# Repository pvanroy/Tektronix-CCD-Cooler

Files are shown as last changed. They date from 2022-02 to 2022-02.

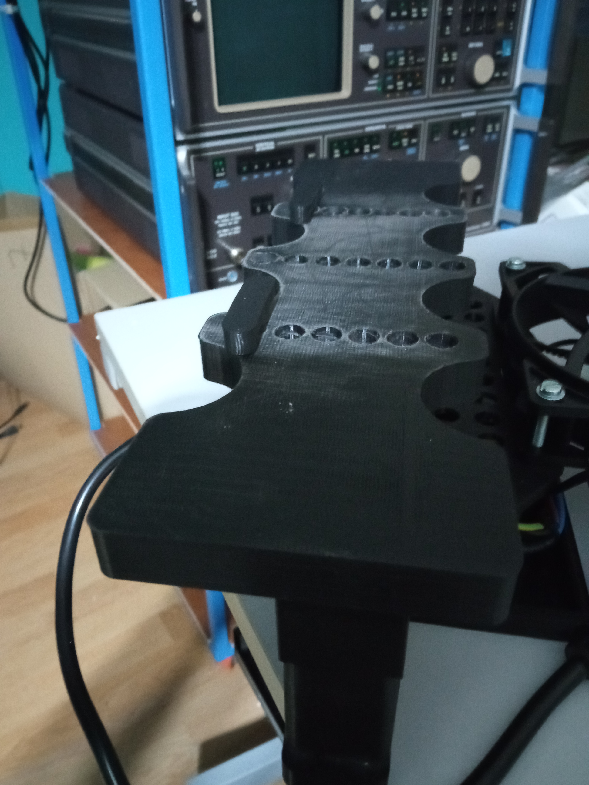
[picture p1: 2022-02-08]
Pictures/IMG_20220208_131840.jpg

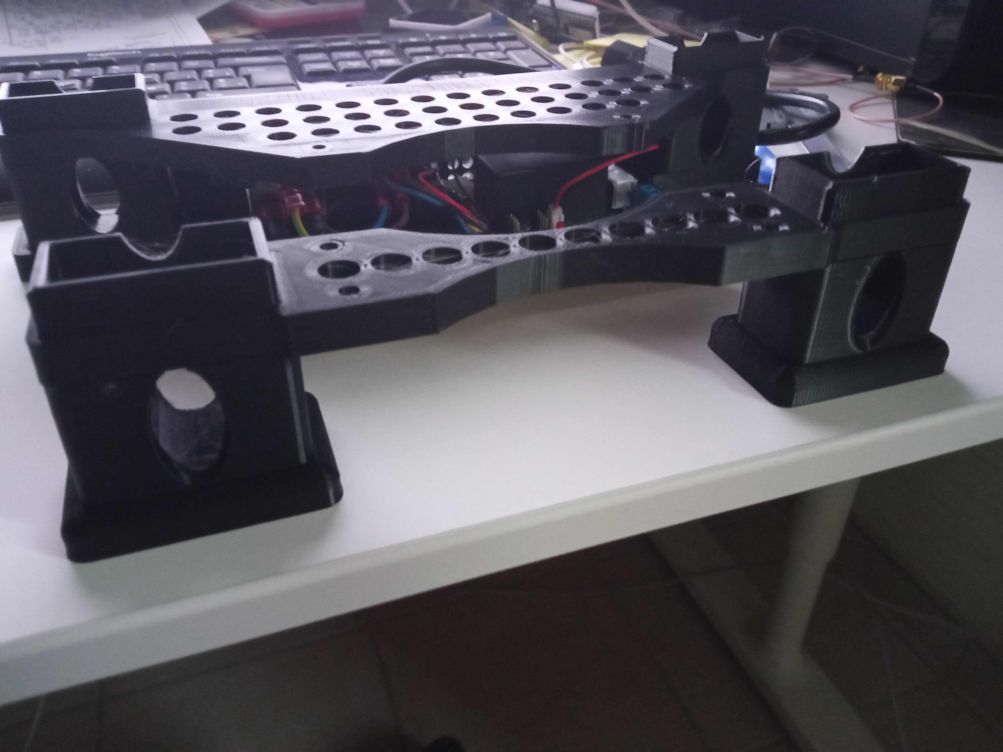
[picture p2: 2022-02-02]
Pictures/IMG_20220201_171502.jpg

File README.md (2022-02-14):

# Tektronix-CCD-Cooler
If you own a Tektronix 24xx series and you attempt a full calibration or just a repair, you have to be careful about the CCD memory section over heating!! This device will help you.
The "Cooler" is a 3D printed kit I designed. It’s made of several parts.
Two fans (120mmx120mmx25mm), are the main elements for this project. They are drived by a small switched power supply running 12V at 850mA. Fans are 120mA nominal consumption (per fan). A power cord is added to the rear for easily powered the scope under test. You can also add a speed controller at your discretion, there is room for it!

Title

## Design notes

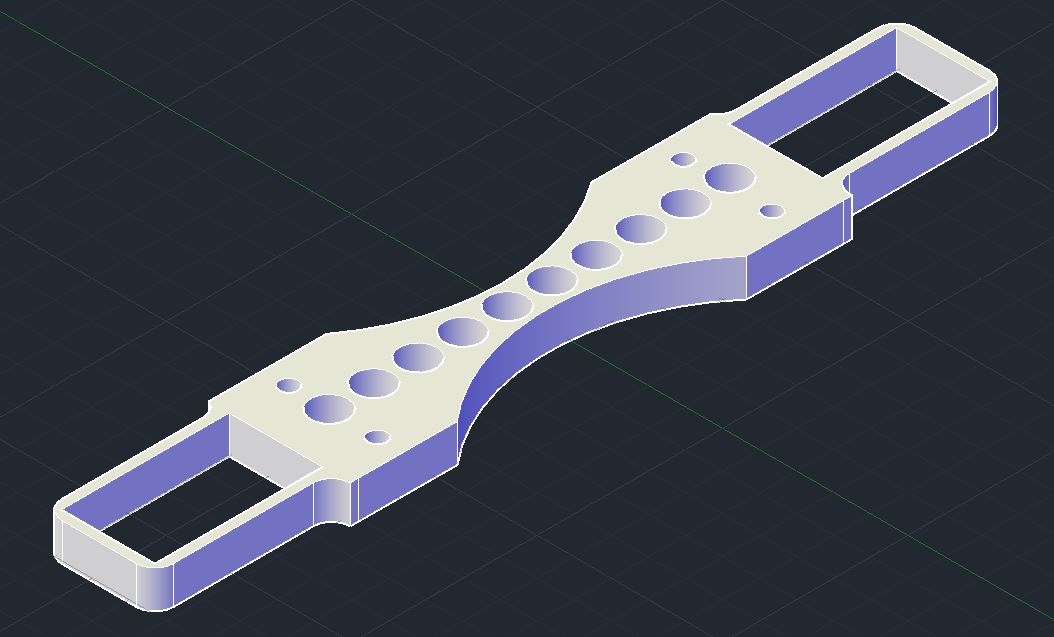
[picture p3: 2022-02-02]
Pictures/Center_Vent_Plate.JPG

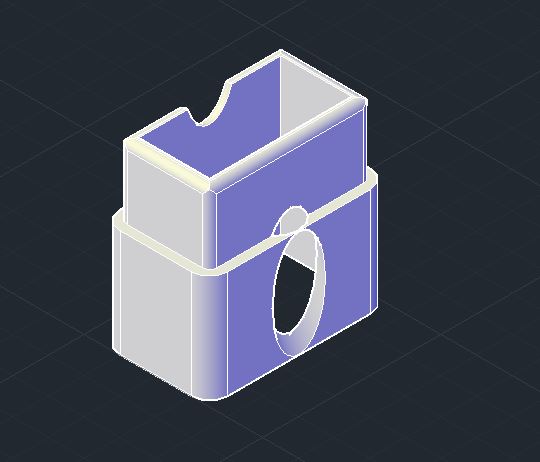
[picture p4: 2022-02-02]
Pictures/Feet.JPG

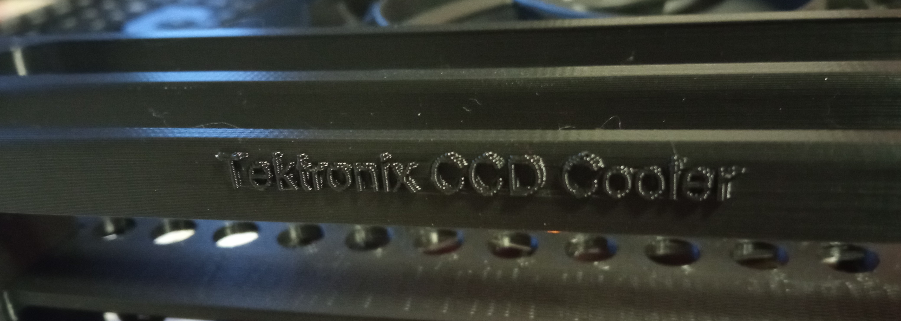
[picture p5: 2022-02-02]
Pictures/Title.jpg

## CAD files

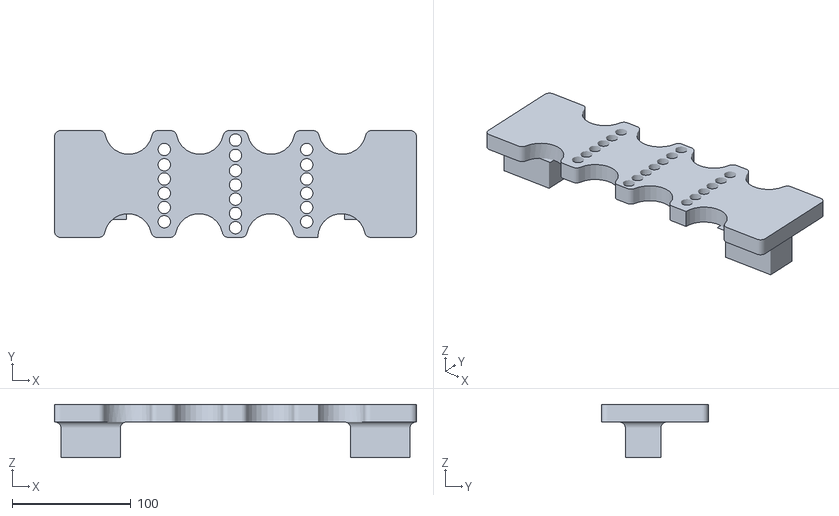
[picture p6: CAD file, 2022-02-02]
Stl's/CoolerBase_V1.1TowerSystem_TopRear.stl
305.0 x 90.0 x 45.0

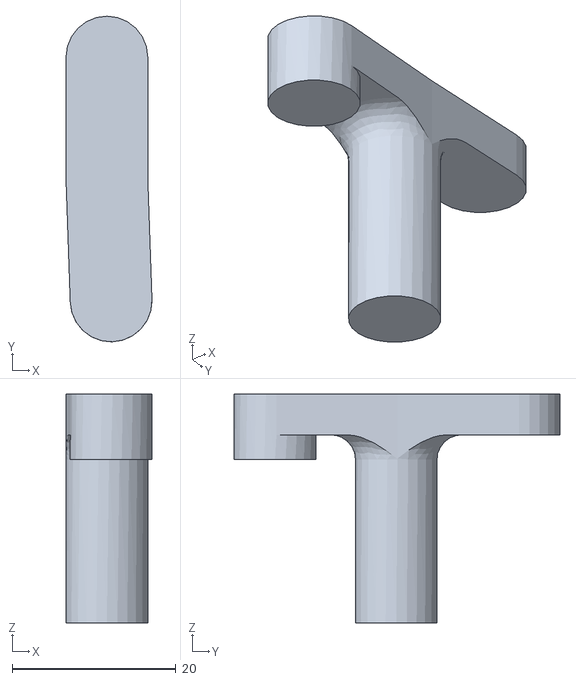
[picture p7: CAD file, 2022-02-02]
Stl's/CoolerBase_V1.1TowerSystem_Clamp.stl
10.5 x 39.8 x 28.0

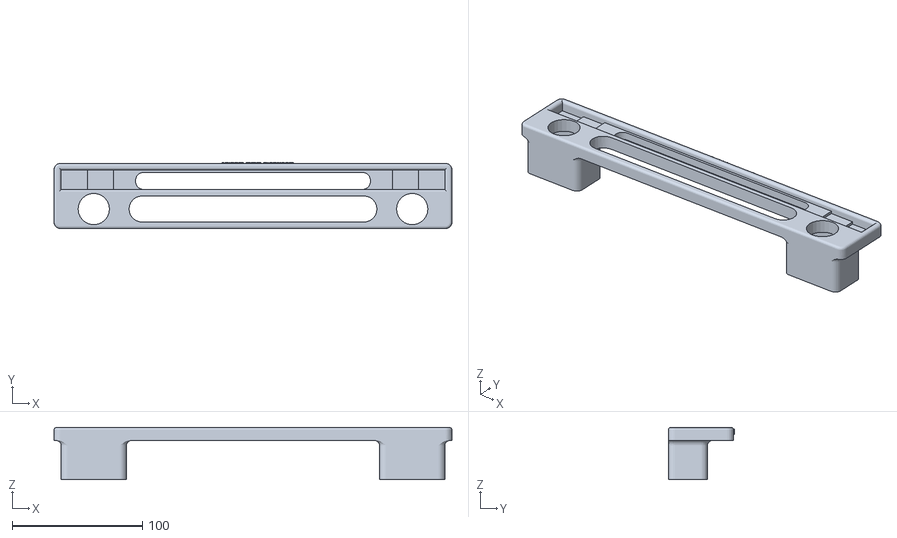
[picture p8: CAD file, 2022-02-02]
Stl's/CoolerBase_V1.1TowerSystem_TopFront.stl
305.0 x 50.8 x 40.0

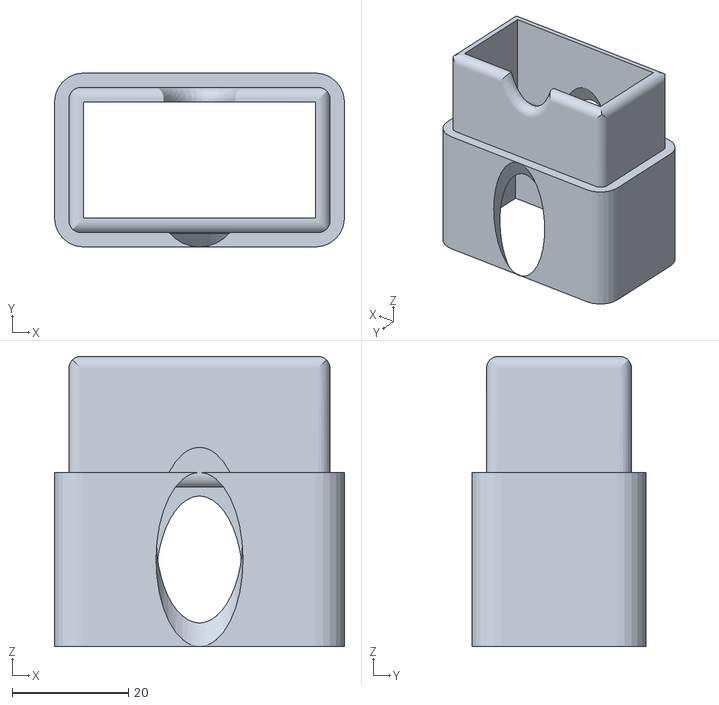
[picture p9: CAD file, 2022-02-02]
Stl's/Cooler_Base_V1.0_Tower_System_Columns.stl
50.0 x 30.0 x 50.0

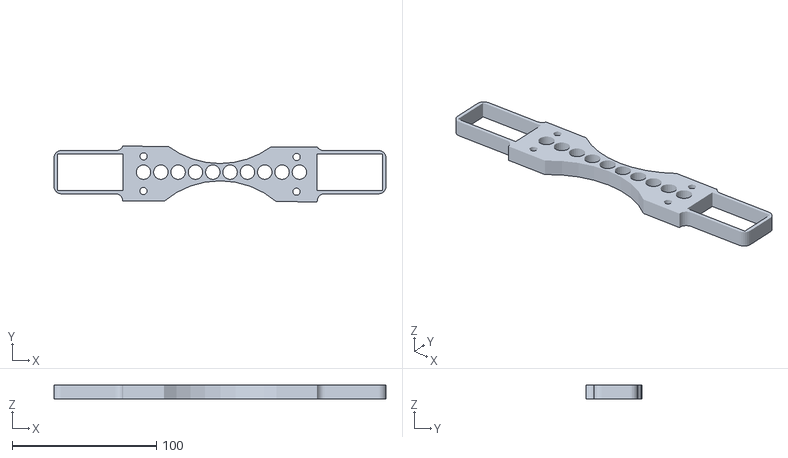
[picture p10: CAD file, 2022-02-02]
Stl's/Cooler_Base_V1.0_Tower_System_CenterVent.stl
230.0 x 38.5 x 10.00

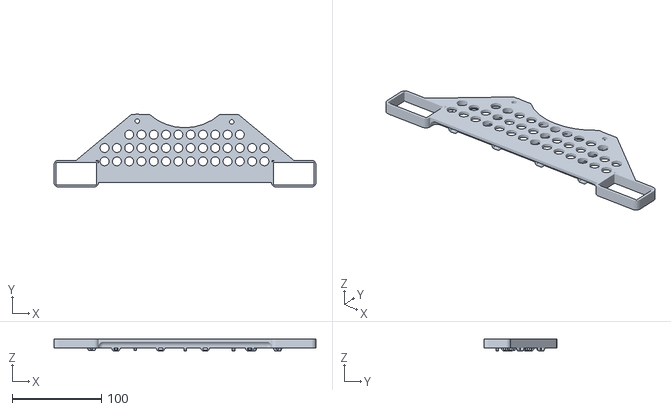
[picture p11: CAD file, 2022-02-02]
Stl's/Cooler_Base_V1.0_Tower_System_FrontVent.stl
294.0 x 81.9 x 13.0

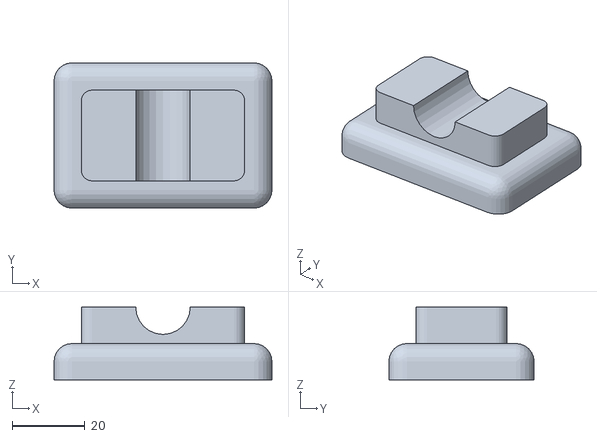
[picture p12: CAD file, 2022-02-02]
Stl's/CoolerBase_V1.1TowerSystem_Feet.stl
60.0 x 40.0 x 20.0

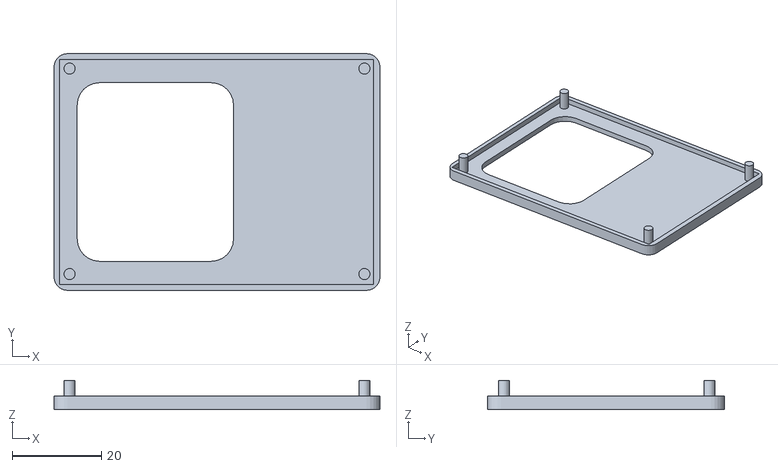
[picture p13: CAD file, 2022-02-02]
Stl's/CoolerBase_V1.1TowerSystem_Board_Support.stl
73.0 x 53.0 x 6.50

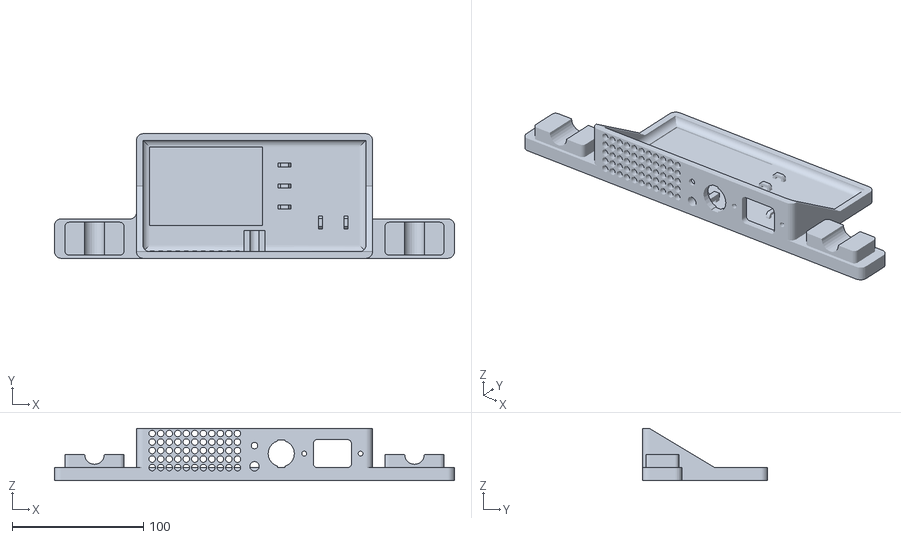
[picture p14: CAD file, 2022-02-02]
Stl's/Cooler_Base_V1.0_Tower_System_Power.stl
305.0 x 95.0 x 40.0

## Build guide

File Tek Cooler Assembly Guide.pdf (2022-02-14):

| 2022

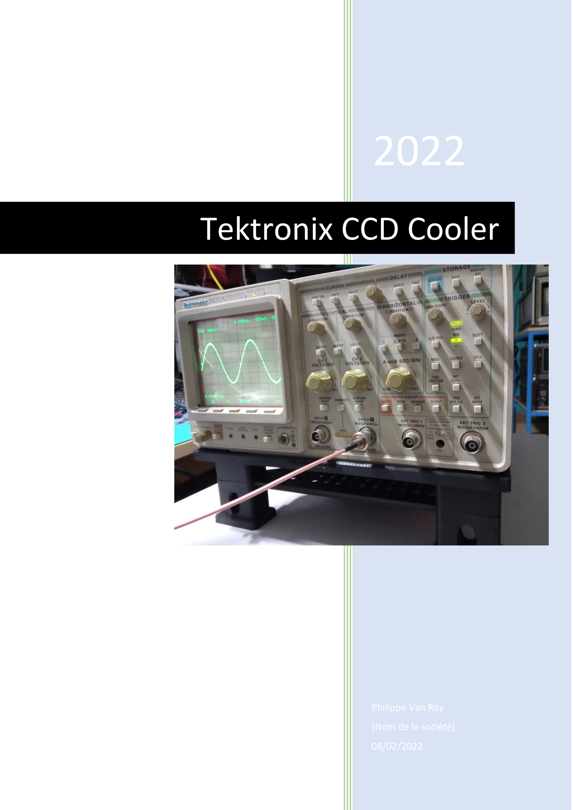
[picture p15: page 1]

# Tektronix CCD Cooler

Philippe Van Roy

[Nom de la société]

08/02/2022

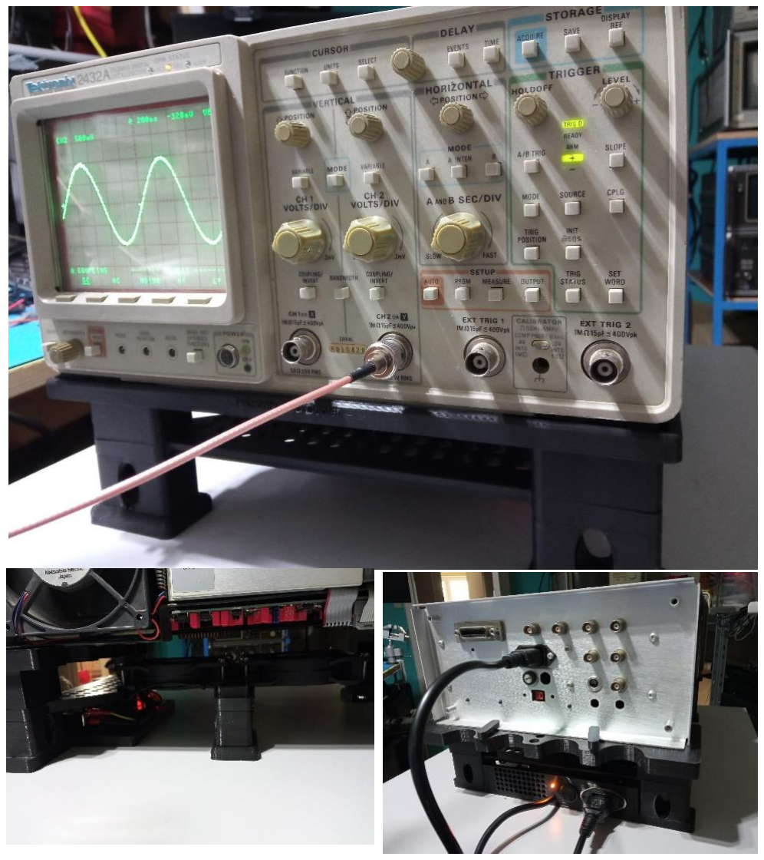
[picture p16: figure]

Philippe Van Roy, Belgium 2022 join our group : https://www.facebook.com/groups/570538600220141

TEKTRONIX CCD COOLER

Tektronix® CCD Cooler (Refroidisseur de CCD Tektronix)

If you own a Tektronix 24xx series and you attempt a full calibration or just a repair, you have to be careful about the CCD memory section over heating!! This device will help you.
The "Cooler" is a 3D printed kit I designed. It’s made of several parts.
Two fans (120mmx120mmx25mm), are the main elements for this project. They are drived by a small switched power supply running 12V at 850mA. Fans are 120mA nominal consumption (per fan). A power cord is added to the rear for easily powered the scope under test. You can also add a speed controller at your discretion, there is room for it!

Si vous possédez la série Tektronix 24xx et que vous avez un étalonnage ou que vous réparez cet appareil, vous devez vous soucier de la section mémoire CCD! (Surchauffe)
Le « Cooler » est une sorte de kit de différentes parties composants sont fabriqués avec une imprimante 3D. Deux ventilateurs (120mmx120mmx25mm), sont le fait principal pour ce projet. Ils sont entraînés par une petite alimentation à découpage de 12V / 850mA. Les ventilateurs ont une consommation nominale de 120 mA (/ventilateur). Un cordon d’alimentation est ajouté à l’arrière pour faciliter l’alimentation du scope à tester. Vous avez l’opportunité d’ajouter un régulateur de vitesse, il est possible de le faire !

EN

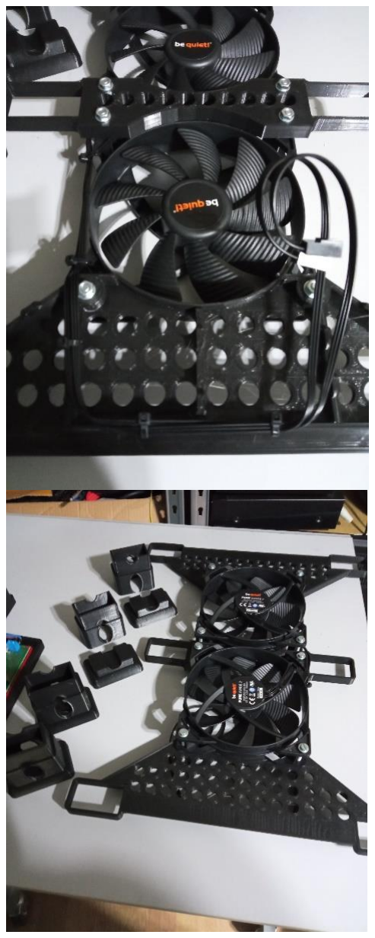
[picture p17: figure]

First of all, Print the parts . In my case, I’ve use Atrillery® Sidewinder X2 with Black PLA+ from E-Sun®.
Of course this printing takes a lot of time (more than 24h !!). PLA consumption is about ¾ of a 1kg reel with thickness of walls of 0.65mm and 12% of filling

After that, assembly of the mechanical parts, assemble front centre and rear vent supports with the two fans.
On the bottom of front and rear vent support there are some cable ties older for a clean cabling.
Assemble four feet with the four legs. They are some holes in the legs if you decide to feed your cables into the legs.

FR
En premier lieu, Imprimer les pièces. Dans mon cas, j’ai utilisé Atrillery Sidewinder X2 avec Black PLA+ d’E-Sun.
Bien sûr cette impression prend beaucoup de temps (plus de 24h !!). La consommation de PLA est d’environ 3/4 d’une bobine de 1kg, avec une épaisseur de parois de 0,65 mm et 12% de remplissage

Après cela, assemblage des pièces mécaniques, assemblage des supports d’aération avant centraux et arrière avec les deux ventilateurs. Sur le bas du support d’évent avant et arrière, il y a des supports de colsons pour un câblage propre.
Assemblez 4 pieds avec quatre «jambes». Il y a des trous dans les jambes si vous décidez de faire passer vos câbles dans les jambes.

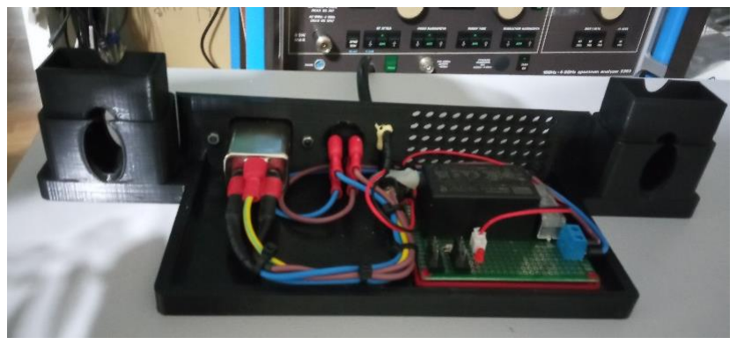
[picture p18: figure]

EN

Assemble the PSU support with two legs (no feet needed).

FR

Assemblez le support du bloc d’alimentation avec deux jambes (pas besoin de pieds).

EN

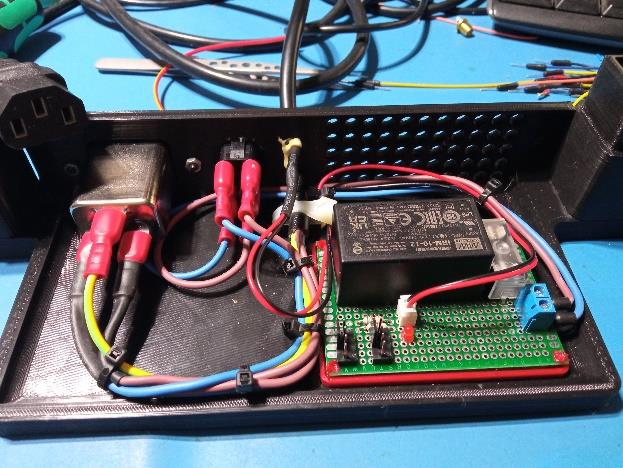
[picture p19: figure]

Assembly of the power supply section; assemble the proto board with connectors, the switching PS, resistor for the limiting current of LED, fuses holder . Cabling 230v (or 120v US) AC parts . Power cable for the scope is directly connected to the Schaffner, so you don’t ave to power up the fan supply the scope under test

FR

Assemblage de la section d’alimentation ; assemblez la carte proto avec connecteurs , le PS à découpage, la résistance pour la LED, le porte-fusibles. Le Câblage 230v (ou 120v US) pièces AC . Le câble d’alimentation du scope est directement connecté au Schaffner, de sorte que vous n’avez pas besoin d’alimenter les ventilateurs pour alimenter le scope sous test.

EN

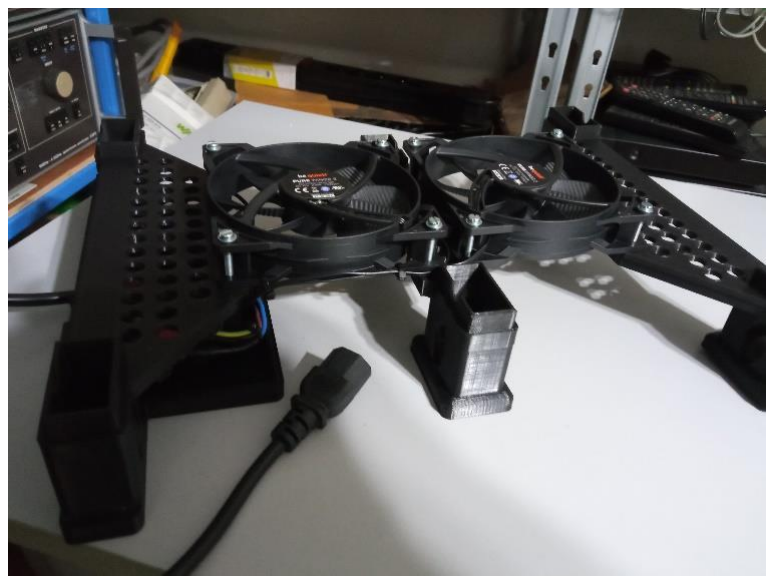
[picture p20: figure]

Connect the fans
to the Proto board
and assemble the
“first floor”

FR

Connectez les
ventilateurs à la
carte Proto et

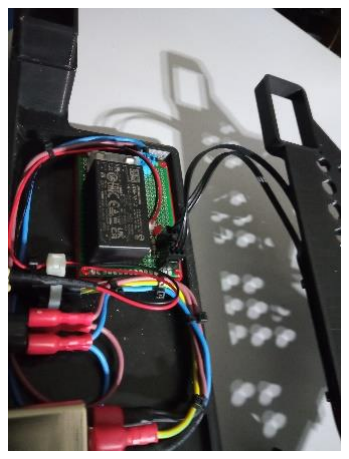
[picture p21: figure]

assemblez le « premier étage »

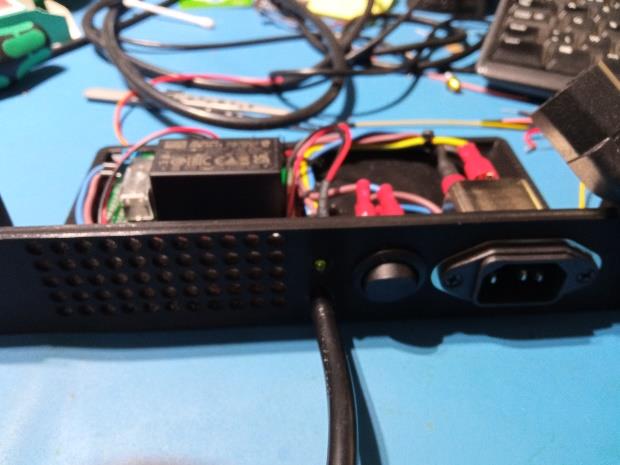
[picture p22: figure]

EN

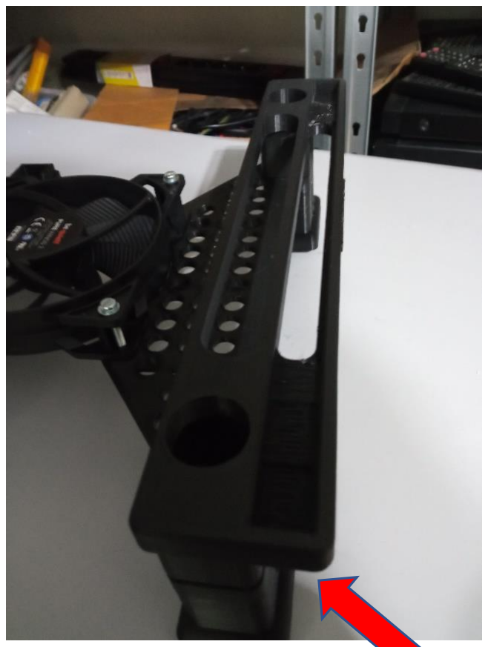
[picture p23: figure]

Assemble the “first floor” with the Top front part at the opposite of the power supply, with over size width at external side (of the front , see picture to have the right position for the scope feets).

Assemble the last part (rear Top parts) with over size width at external side (of the rear; see picture)

Note the extra “Rear Lock Key” to clamp the scope on the rear base.

FR

Assemblez le « premier étage » avec la partie avant supérieure à l’opposé de l’alimentation, avec une largeur surdimensionnée sur le côté extérieur (de l’avant, voir l’image pour obtenir la bonne position pour les pieds du scope)

Notez la « Clé de verrouillage arrière » supplémentaire pour serrer la lunette sur la base arrière.

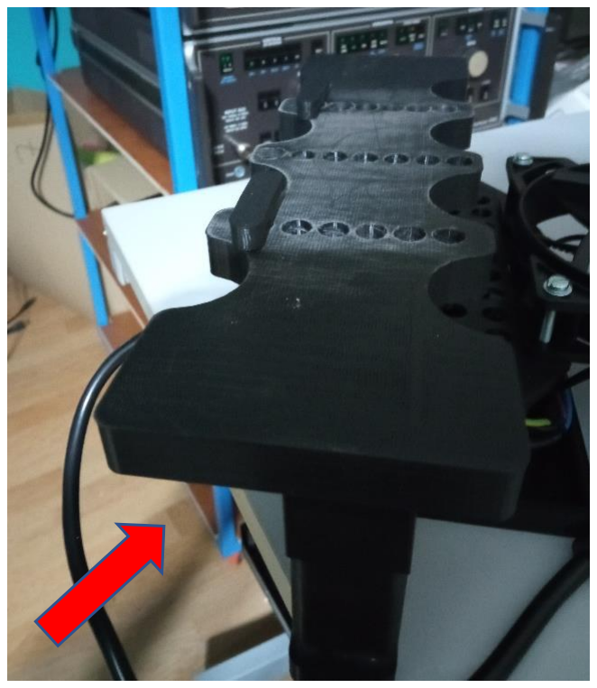
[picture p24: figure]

Part list

Structure
4 Feet
1 Rear PSU/ feet
6 Legs
2 Front / rear fan support 1 Intrmediate fan support
1 Top front scope support
1 Top rear scope support
2 (3) Rear lock key
8 M4 Nuts – bold + 16 washer
PSU
1 Schaffner,3A,250 V ac Male Panel Mount IEC Filter 1 bipolar power switch
1 IEC C13 power cord
1 proto board
1 fuse holder (20mm) + 250mA fuse tube 20mm 1 Switching PS, MEAN WELL; IRM-10-12
1 Resistor 1/4w R560
2 PCB male 4Pins Fan connector
1 PCB male JST 2 pin (Led), + ascocieted cable 2 Fan (PC) 120x120x25mm (<250mA)

Structure
4 pieds
1 bloc d’alimentation arrière / pieds
6 jambes
2 Support de ventilateur avant / arrière
1 Prise en charge des ventilateurs Intermédiate 1 Support de scope frontale
1 Support de scope arrière
2 (3) Verrouillage arrière
8 écrous M4 – gras + 16 rondelles
PSU
1 Filtre secteur Schaffner,3A,250 V ac Mâle 1 interrupteur bipolaire.
1 cordon d’alimentation IEC C13
1 PCB proto
1 porte-fusible (20mm) + tube de fusible 250mA 20mm 1 Alim découpage, MEAN WELL; IRM-10-12
1 Resistance 1/4w R560
2 PCB mâle 4Pins Connecteur ventilateur de PC
1 PCB mâle JST 2 broches (Led), + câble associé 2 Ventilateur (PC) 120x120x25mm (<250mA)
